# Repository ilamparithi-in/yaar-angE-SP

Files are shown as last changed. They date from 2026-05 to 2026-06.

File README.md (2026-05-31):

# yaar-angE-SP
Yaar ange? [Who's there?] - IoT attachment for primitive AC Calling Bell (Doorbell) 

\[README.md coming soon :P\]

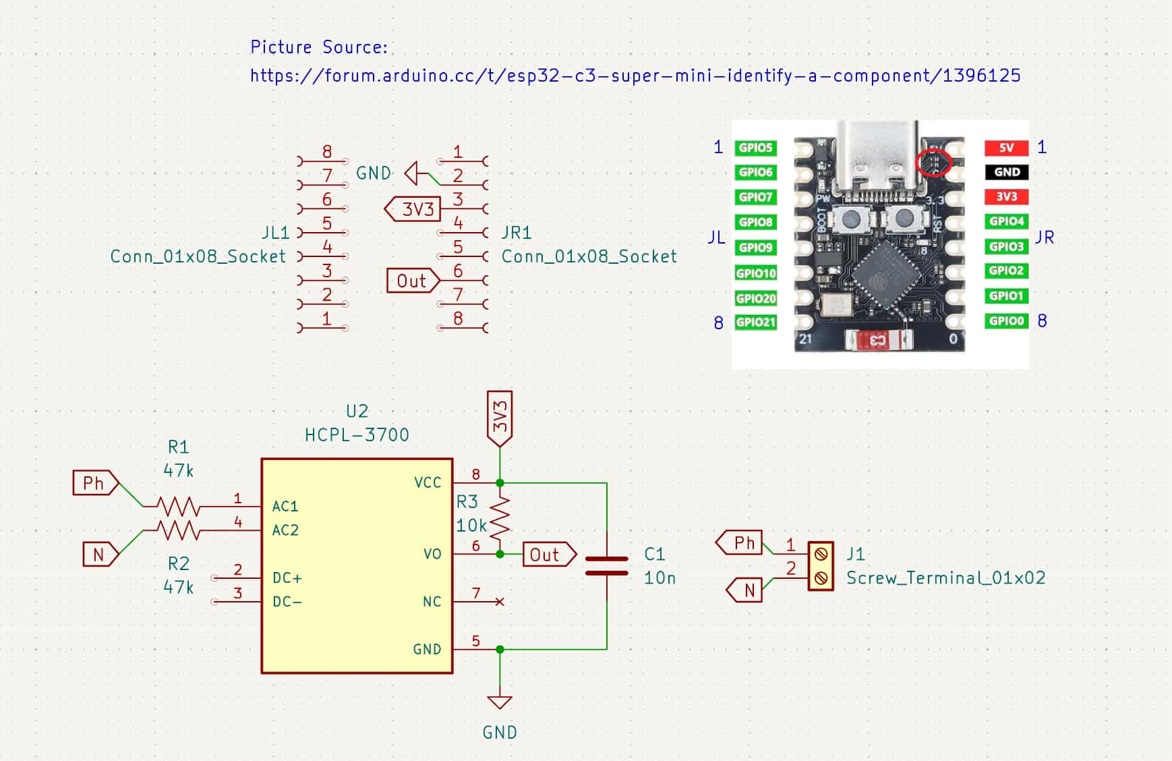
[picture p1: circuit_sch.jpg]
Schematic


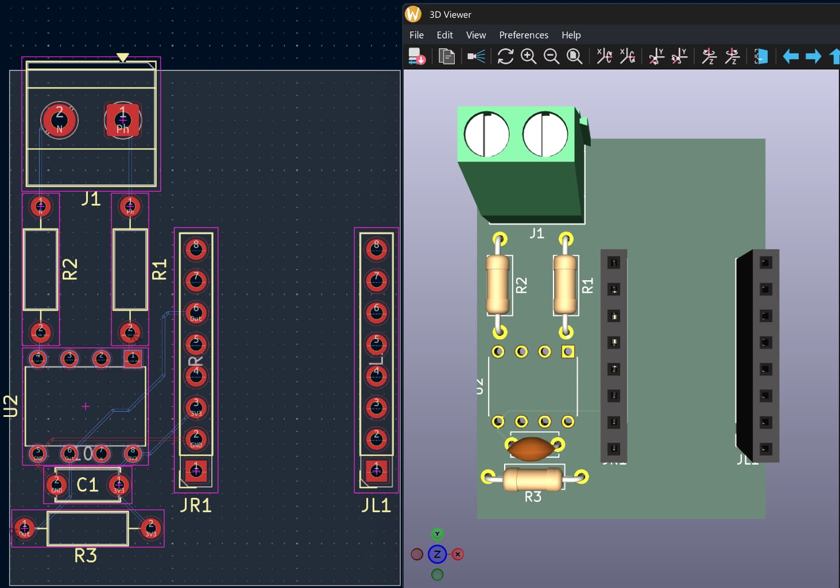
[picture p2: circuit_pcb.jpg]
PCB Design


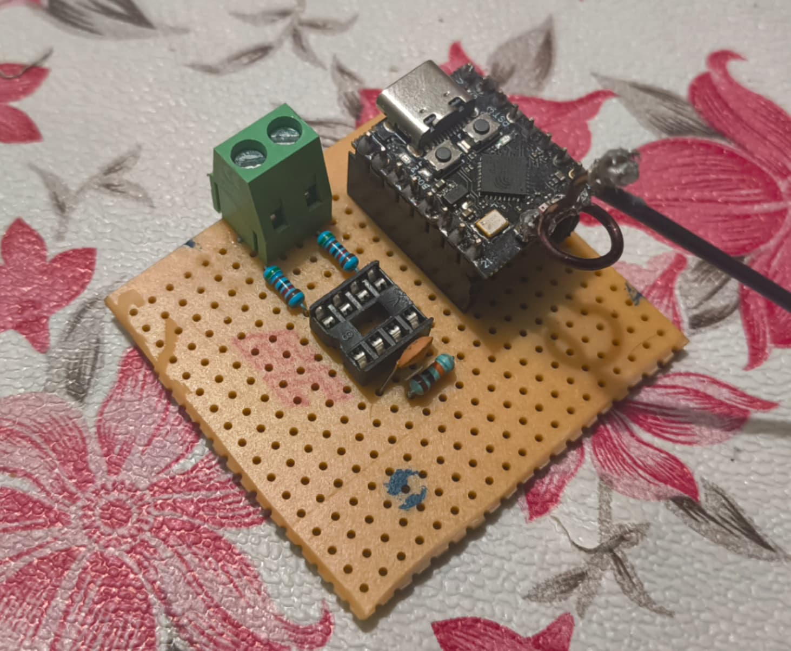
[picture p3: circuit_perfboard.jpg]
PerfBoard


<center>(IC missing :P and Antenna modification for better signal strength)

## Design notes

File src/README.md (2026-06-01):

The loop version was created before I got to know about interrupts. It is unnecessarily aggressive on the input detection.

The interrupt version is preferred for usage. Note that for communication over https there are additional changes to be made in the code (described in comments).

Add (uncomment) this before `WiFi.begin()` for stabilising ESP32-C3 Supermini WiFi connection. (Suggestion by [Mario's Ideas](youtube.com/watch?v=IzLD6f8cDHs&t=420))
```cpp
    WiFi.setTxPower(WIFI_POWER_8_5dBm);
```

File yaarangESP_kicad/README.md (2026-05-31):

Download the symbol and footprint of the HCPL3700 from here: https://www.snapeda.com/parts/HCPL-3700/Broadcom/view-part

Schematic made in KiCad 10.0

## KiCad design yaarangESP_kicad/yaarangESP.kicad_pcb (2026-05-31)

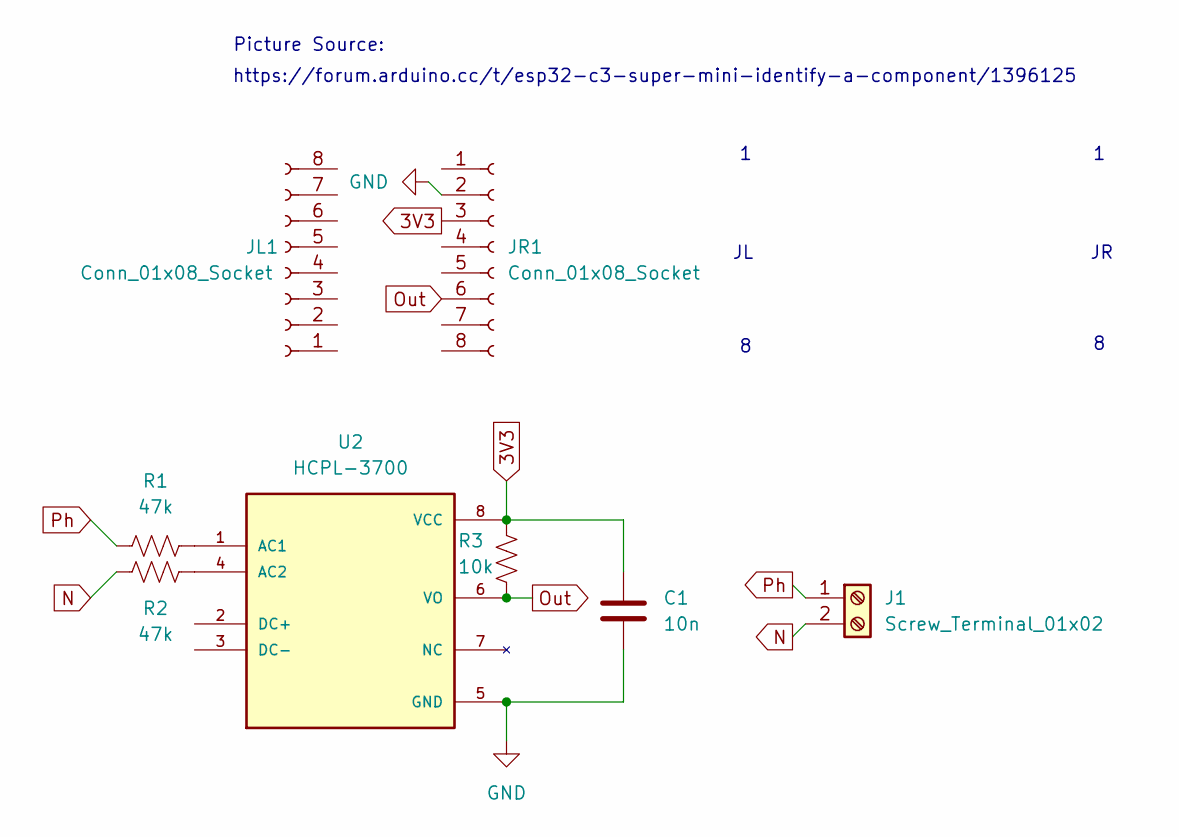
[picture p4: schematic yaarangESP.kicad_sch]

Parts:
C1: 10n; C_Disc_D5.0mm_W2.5mm_P5.00mm
J1: Screw_Terminal_01x02; TerminalBlock_Phoenix_MKDS-1,5-2-5.08_1x02_P5.08mm_Horizont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
JL1: Conn_01x08_Socket; PinSocket_1x08_P2.54mm_Vertical
JR1: Conn_01x08_Socket; PinSocket_1x08_P2.54mm_Vertical
R1, R2: 47k; R_Axial_DIN0207_L6.3mm_D2.5mm_P10.16mm_Horizontal
R3: 10k; R_Axial_DIN0207_L6.3mm_D2.5mm_P10.16mm_Horizontal
U2: HCPL-3700; DIP762W65P254L990H470Q8; PARTREV N/A

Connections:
3V3: C1.1, JR1.3, R3.2, U2.8 (VCC)
GND: C1.2, JR1.2, U2.5 (GND)
N: J1.2, R2.1
unnamed: R1.2, U2.1 (AC1)
unnamed: R2.2, U2.4 (AC2)
Out: JR1.6, R3.1, U2.6 (VO)
Ph: J1.1, R1.1

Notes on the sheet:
Picture Source:
https://forum.arduino.cc/t/esp32-c3-super-mini-identify-a-component/1396125

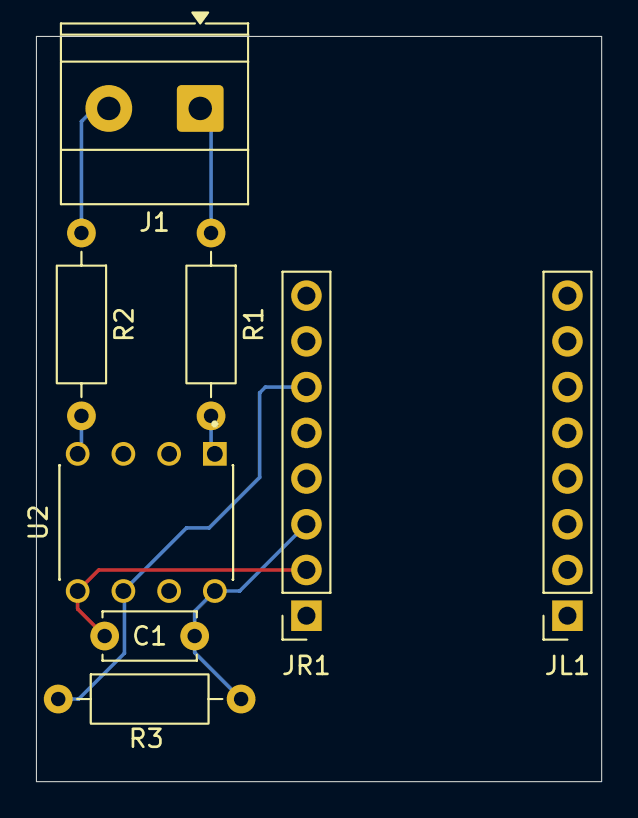
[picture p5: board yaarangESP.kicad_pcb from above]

Board: 2 copper layers, 31.4 x 41.4 mm, 8 parts (0 on the bottom side), 7 nets.

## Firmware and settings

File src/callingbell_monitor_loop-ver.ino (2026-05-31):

#include <Arduino.h>
#include <WiFi.h>
#include <HTTPClient.h>
#include "freertos/FreeRTOS.h"
#include "freertos/task.h"
#include "freertos/queue.h"
#include <time.h>

//\\ Debug Logging //\\
// Set to 1 to enable verbose serial diagnostics; 0 for silent production mode.
#define DEBUG_LOG 0
#if DEBUG_LOG
  #define DLOG(fmt, ...)  Serial.printf(fmt, ##__VA_ARGS__)
  #define DLOGLN(s)       Serial.println(s)
  #define DLOGP(s)        Serial.print(s)
#else
  #define DLOG(fmt, ...)  ((void)0)
  #define DLOGLN(s)       ((void)0)
  #define DLOGP(s)        ((void)0)
#endif

//\\ Configuration //\\

// Hardware
static constexpr uint8_t  CPU_FREQ_MHZ            = 80;   // lower frequency reduces idle heat
static constexpr uint8_t  BELL_PIN                = 4;
static constexpr uint8_t  STATUS_LED_PIN          = 2;
// Set to true  if the LED turns on when the pin is HIGH (most external LEDs).
// Set to false if the LED turns on when the pin is LOW  (some built-in LEDs).
static constexpr bool     LED_ACTIVE_HIGH         = true;

// Input timing (milliseconds)
// POLL_INTERVAL_MS: sampling interval used by inputTask while actively polling
// after an interrupt. For AC zero-crossing signals, keep > the AC period so
// each sample sees a stable half-cycle:  50 Hz => > 10 ms,  60 Hz => > 8 ms
static constexpr uint32_t POLL_INTERVAL_MS        = 20;
static constexpr uint32_t DEBOUNCE_MS             = 100;
static constexpr uint32_t REARM_MS                = 300;
static constexpr uint32_t MIN_EVENT_INTERVAL_MS   = 2000;

// Queue
static constexpr UBaseType_t QUEUE_SIZE           = 16;

// Delivery
static constexpr uint8_t  MAX_RETRIES             = 3;
static constexpr uint32_t RETRY_DELAY_MS          = 2000;
static constexpr uint32_t REQUEUE_COOLDOWN_MS     = 30000;

// Time
static const char*        NTP_SERVER              = "time.google.com";
static constexpr uint32_t NTP_RETRY_INTERVAL_MS   = 10000;
static constexpr uint32_t NTP_WAIT_TIMEOUT_MS     = 30000;

// Network credentials - replace before deployment
static const char*        WIFI_SSID               = "airtelblack.com";
static const char*        WIFI_PASSWORD           = "nice_website_lol";
static const char*        BACKEND_URL             = "http://192.168.1.69/iot/callingbell";
static const char*        BEARER_TOKEN            = "purpose_specific_system_write_your_own_code";
static const char*        BELL_LOCATION           = "Sorkkavaasal (Heaven's Entrance)";

//\\ Data Model //\\

struct BellEvent {
    uint32_t      id;
    unsigned long millisAtDetection;  // monotonic capture time (millis())
};

//\\ Shared State between producer and consumer //\\

volatile bool timeSynced       = false;  // wall clock is valid
volatile bool ntpSyncRequested = false;  // ntpTask should attempt sync

QueueHandle_t bellQueue = nullptr;

//\\ Input State //\\

enum BellState { IDLE, ARMED };

static BellState     bellState          = IDLE;
static int           lastRawState       = HIGH;   // pull-up: idle is HIGH
static int           stableState        = HIGH;
static unsigned long lastRawChange      = 0;
static bool          trackingRelease    = false;
static unsigned long releaseStableSince = 0;
static unsigned long lastAcceptedEvent  = 0;      // 0 = no event yet
static uint32_t      nextEventId        = 1;


//\\ LED Feedback //\\

/* Write a logical LED state (true = on) respecting LED_ACTIVE_HIGH. */
static inline void ledWrite(bool on) {
    digitalWrite(STATUS_LED_PIN, (on == LED_ACTIVE_HIGH) ? HIGH : LOW);
}

/**
 * Blink the LED count times, then restore the idle-connected state (OFF).
 * Must only be called from an RTOS task context (uses vTaskDelay).
 */
static void blinkLed(int count, uint32_t onMs, uint32_t offMs) {
    for (int i = 0; i < count; ++i) {
        ledWrite(true);
        vTaskDelay(pdMS_TO_TICKS(onMs));
        ledWrite(false);
        vTaskDelay(pdMS_TO_TICKS(offMs));
    }
}

static void blinkSuccess() { blinkLed(2, 150, 100); }

// Solid ON for 500ms
static void blinkFailure() {
    ledWrite(true);
    vTaskDelay(pdMS_TO_TICKS(500));
    ledWrite(false);
}

// Check out https://github.com/ilamparithi-in/currentu-pochino !
static void startupChime() {
    ledWrite(true);  delay(500);  ledWrite(false);
    for (int i = 0; i < 10; i++) {
        delay(20);  ledWrite(true);  delay(50);  ledWrite(false);
    }
    delay(500);  ledWrite(true);  delay(100);  ledWrite(false);
}

//\\ Event Delivery //\\

/**
 * Reconstruct the event epoch, serialise to JSON, and POST to the backend.
 *
 * Returns true  implies event can be discarded (HTTP 200 / 409 / 401).
 * Returns false implies transient failure; caller should retry.
 *
 * NOTE: For HTTPS, replace http.begin(BACKEND_URL) with
 *       http.begin(wifiClientSecure, BACKEND_URL) and supply a CA certificate.
 */
static bool sendEvent(const BellEvent& event) {
    if (WiFi.status() != WL_CONNECTED) {
        DLOGLN("[DELIVERY] no WiFi - skipping");
        return false;
    }

    // Reconstruct epoch at press time from current wall clock + elapsed millis
    const unsigned long elapsedMs = millis() - event.millisAtDetection;
    const time_t nowEpoch         = time(nullptr);
    const time_t eventEpoch       = nowEpoch - static_cast<time_t>(elapsedMs / 1000);

    char payloadBuf[64];
    snprintf(payloadBuf, sizeof(payloadBuf),
             "{\"id\":%u,\"timestamp\":%ld}",
             event.id, static_cast<long>(eventEpoch));
    const String payload(payloadBuf);

    HTTPClient http;
    http.begin(BACKEND_URL);
    http.addHeader("Content-Type", "application/json");
    http.addHeader("Authorization", String("Bearer ") + BEARER_TOKEN);
    http.addHeader("X-Bell-Location", BELL_LOCATION);
    http.setTimeout(10000);

    const int httpCode = http.POST(payload);
    http.end();

    DLOG("[DELIVERY] id=%u  http=%d\n", event.id, httpCode);

    if (httpCode == 200 || httpCode == 409) {
        // 200 = accepted; 409 = duplicate already recorded - both are success
        blinkSuccess();
        return true;
    }

    if (httpCode == 401) {
        // Credentials will not self-heal; drop event to avoid queue saturation
        DLOGLN("[DELIVERY] 401 auth failure - check BEARER_TOKEN, dropping event");
        blinkFailure();
        return true;
    }

    // All other codes (5xx, network error, timeout) are transient
    blinkFailure();
    return false;
}

//\\ RTOS Task: Network Consumer //\\

/**
 * Pulls events from bellQueue, waits for wall-clock validity, delivers via
 * HTTP with retry, and requeues to the front on max-retry exhaustion.
 */
static void networkTask(void* /*param*/) {
    BellEvent event;

    for (;;) {
        // Block indefinitely until an event arrives
        if (xQueueReceive(bellQueue, &event, portMAX_DELAY) != pdTRUE) {
            continue;
        }

        DLOG("[NETWORK] dequeued id=%u\n", event.id);

        // Defer until wall clock is valid to guarantee correct timestamps
        while (!timeSynced) {
            DLOGLN("[NETWORK] waiting for time sync...");
            vTaskDelay(pdMS_TO_TICKS(1000));
        }

        bool    delivered = false;
        uint8_t retries   = 0;

        while (!delivered && retries < MAX_RETRIES) {
            delivered = sendEvent(event);
            if (!delivered) {
                ++retries;
                DLOG("[NETWORK] retry %u/%u for id=%u\n",
                     retries, MAX_RETRIES, event.id);
                vTaskDelay(pdMS_TO_TICKS(RETRY_DELAY_MS));
            }
        }

        if (!delivered) {
            DLOG("[NETWORK] max retries reached - requeueing id=%u\n", event.id);
            // Push to front so this event is attempted before any newer ones
            if (xQueueSendToFront(bellQueue, &event, 0) != pdTRUE) {
                DLOGLN("[NETWORK] queue full - event dropped");
            }
            // Cool-off before the front-of-queue event is tried again
            vTaskDelay(pdMS_TO_TICKS(REQUEUE_COOLDOWN_MS));
        }
    }
}

//\\ RTOS Task: NTP Synchronisation //\\

/**
 * Watches ntpSyncRequested and drives NTP synchronisation.
 * Runs independently of Wi-Fi callbacks to avoid watchdog issues.
 */

// The implementation in this version is inefficient and has been replaced with a no loop task in the interrupt ver.
static void ntpTask(void* /*param*/) {
    for (;;) {
        if (ntpSyncRequested) {
            ntpSyncRequested = false;
            DLOGLN("[NTP] attempting synchronisation...");

            configTime(0, 0, NTP_SERVER);

            struct tm   timeinfo;
            bool        synced       = false;
            unsigned long attemptStart = millis();

            while ((millis() - attemptStart) < NTP_WAIT_TIMEOUT_MS) {
                if (getLocalTime(&timeinfo, 1000)) {
                    synced = true;
                    break;
                }
                vTaskDelay(pdMS_TO_TICKS(1000));
            }

            if (synced) {
                timeSynced = true;
                DLOG("[NTP] synced - %04d-%02d-%02d %02d:%02d:%02d UTC\n",
                     timeinfo.tm_year + 1900, timeinfo.tm_mon + 1, timeinfo.tm_mday,
                     timeinfo.tm_hour,        timeinfo.tm_min,      timeinfo.tm_sec);
            } else {
                DLOGLN("[NTP] timed out - will retry");
                ntpSyncRequested = true;  // reschedule
            }
        }

        vTaskDelay(pdMS_TO_TICKS(NTP_RETRY_INTERVAL_MS));
    }
}

//\\ Wi-Fi Event Handler //\\

static void onWiFiEvent(WiFiEvent_t event) {
    switch (event) {
        case ARDUINO_EVENT_WIFI_STA_GOT_IP:
            DLOGP("[WIFI] connected  IP=");
            DLOGLN(WiFi.localIP());
            ledWrite(false);  // connected -> LED OFF
            ntpSyncRequested = true;
            break;

        case ARDUINO_EVENT_WIFI_STA_DISCONNECTED:
            DLOGLN("[WIFI] disconnected");
            timeSynced       = false;
            ntpSyncRequested = false;
            ledWrite(true);   // disconnected -> LED ON
            WiFi.reconnect();
            break;

        default:
            break;
    }
}

//\\ Input //\\

static void acceptPress(unsigned long nowMs) {
    BellEvent ev{};
    ev.id                = nextEventId++;
    ev.millisAtDetection = nowMs;
    lastAcceptedEvent    = nowMs;

    DLOG("[INPUT] press accepted  id=%u\n", ev.id);

    // Non-blocking send; drop newest if queue is full rather than stalling input
    if (xQueueSendToBack(bellQueue, &ev, 0) != pdTRUE) {
        DLOGLN("[INPUT] queue full - event dropped");
    }
}

//\\ Input: Debounce + FSM Polling //\\ 

/**
 * Called from the main Arduino loop (~1 kHz).
 *   1. Debounce window    - raw level must be stable for DEBOUNCE_MS.
 *   2. FSM (IDLE/ARMED)   - one event per press, hold does not repeat.
 *   3. Rearm delay        - stable release must persist for REARM_MS.
 *   4. Global rate cap    - MIN_EVENT_INTERVAL_MS between accepted events.
 *
 * Active-low convention: LOW = pressed, HIGH = released.
 */

// This would later prove to me that this was useless and too aggressive to work properly.
static void processBellInput() {
    const int          rawState = digitalRead(BELL_PIN);
    const unsigned long now     = millis();

    //\\ 1. Debounce
    if (rawState != lastRawState) {
        lastRawState  = rawState;
        lastRawChange = now;
    }

    if ((now - lastRawChange) >= DEBOUNCE_MS && rawState != stableState) {
        stableState = rawState;
    }

    //\\ 2 & 3. Finite State Machine
    if (bellState == IDLE) {
        if (stableState == LOW) {
            //\\ 4. Global rate cap
            const bool rateOk =
                (lastAcceptedEvent == 0) ||
                ((now - lastAcceptedEvent) >= MIN_EVENT_INTERVAL_MS);

            if (rateOk) {
                acceptPress(now);
                bellState = ARMED;
            }
        }

    } else {  // ARMED - waiting for a clean release before rearming
        if (stableState == HIGH) {
            if (!trackingRelease) {
                trackingRelease    = true;
                releaseStableSince = now;
            }

            if ((now - releaseStableSince) >= REARM_MS) {
                bellState       = IDLE;
                trackingRelease = false;
            }
        } else {
            // Re-pressed before rearm elapsed - reset release window
            trackingRelease = false;
        }
    }
}

//\\ Setup //\\

void setup() {
    setCpuFrequencyMhz(CPU_FREQ_MHZ);
    Serial.begin(115200);
    delay(200);
    Serial.println("\n=== Doorbell Monitor Starting ===");
    Serial.printf("CPU = %lu MHz\n", getCpuFrequencyMhz());

    // GPIO
    pinMode(BELL_PIN,       INPUT_PULLUP);
    pinMode(STATUS_LED_PIN, OUTPUT);
    startupChime();
    ledWrite(true);  // start disconnected -> LED ON

    // Seed input state from current pin level to avoid false trigger on boot
    stableState  = digitalRead(BELL_PIN);
    lastRawState = stableState;

    // Shared queue
    bellQueue = xQueueCreate(QUEUE_SIZE, sizeof(BellEvent));
    if (bellQueue == nullptr) {
        Serial.println("FATAL: failed to create bellQueue");
        for (;;) { delay(1000); }
    }

    // Wi-Fi (callback registered before begin so no events are missed)
    WiFi.onEvent(onWiFiEvent);
    WiFi.mode(WIFI_STA);
    WiFi.setSleep(true);  // modem sleep reduces radio power and heat
    WiFi.begin(WIFI_SSID, WIFI_PASSWORD);
    DLOGLN("[WIFI] connecting...");

    // RTOS tasks
    xTaskCreate(ntpTask,     "ntpTask",     4096, nullptr, 1, nullptr);
    xTaskCreate(networkTask, "networkTask", 8192, nullptr, 2, nullptr);

    Serial.println("=== Setup complete ===");
}

//\\ Main Loop (Input Handling) //\\ 

void loop() {
    processBellInput();
    delay(POLL_INTERVAL_MS);  // must be > AC period (> 10 ms for 50 Hz, > 8 ms for 60 Hz)
}

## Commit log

2026-05-31 Upload verified code, images, and KiCad Project
    [yaarangESP.kicad_pcb, yaarangESP.kicad_sch]
2026-06-01 ESP32-C3 Supermini WiFi fix
    [callingbell_monitor_interrupt-ver.ino]
